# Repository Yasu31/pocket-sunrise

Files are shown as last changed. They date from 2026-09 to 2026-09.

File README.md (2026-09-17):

# Pocket Sunrise
[English README](/README-en.md)

自然な明かりで朝起きれる小型デバイス

ここではファームウェアのArduinoスケッチと基板デザイン(KiCad)を公開しています
- プロジェクト: https://yasunori.jp/pocket-sunrise
- 外装部品: https://grabcad.com/library/pocket-sunrise-1
- 動画: https://youtu.be/eCHGJ3ehzJc

## キャンドルライトモード

3つのボタンを同時に押すと、タイマーの状態に関わらずLEDが点灯し、ろうそくのように明るさがかすかに変化するモードに切り替えられます。左右のボタンで明るさを調整できます。

## 電子部品
必要な電子パーツはこちらのスプレッドシートにまとめてあります。すべて秋月電子で買えます。
 →[Pocket Sunrise 電子部品](https://docs.google.com/spreadsheets/d/1AGpVGOaxi01ax8kF4fcREE8NY4uzkjkZFQBg4IJ91os/edit?usp=sharing)

## 基板
私はPCBGOGOに発注しましたがどこでも大丈夫だと思います。5枚発注して（初回割ということもありましたが）送料込みでたった1200円でした。

## 基板実装
以下の写真を参考に実装してください。注意点としては
- LEDの定格内で扱っていて、抵抗での発熱も許容範囲のはずですが、それでも想定外のケースなどで異常発熱する場合もあり得るので、使用時は常にそばにいる状態にしてください。自己責任で使ってください。
- 7セグ用の300Ω抵抗は基板画像の通り一部のみ実装し、それ以外は短絡してください（7セグの向きを後から変えられるようにこの実装になっています）。
- LEDの定格電流的には25Ωの電流制限抵抗は全然許容範囲内なのですが、セメント抵抗の方の発熱が大きかったので、50Ω抵抗を並列で接続して放熱板も取り付けることで発熱を抑えています。画像のように組付ければ、外装パーツ内に収まるはずです（もちろんちゃんとしたLEDドライバを使えば発熱を抑えられるのですが、初めての基板設計ということもあり簡単な回路を優先しました）
- Arduino nanoが基板に挿さったままだとスケッチが書き込めない場合があります。うまく書き込めない場合は、一旦抜いてから書き込んでください。
- LEDは10センチほどのワイヤで基板に接続してください。曲げやすいワイヤの方が外装パーツに挿入しやすいです。
- LEDの裏側にも放熱板を取り付けることをお勧めします。
- M3、長さ12mmのナットとボルト4本で組み立てられます。ゴム足パーツを底に貼ると滑り止めになります。






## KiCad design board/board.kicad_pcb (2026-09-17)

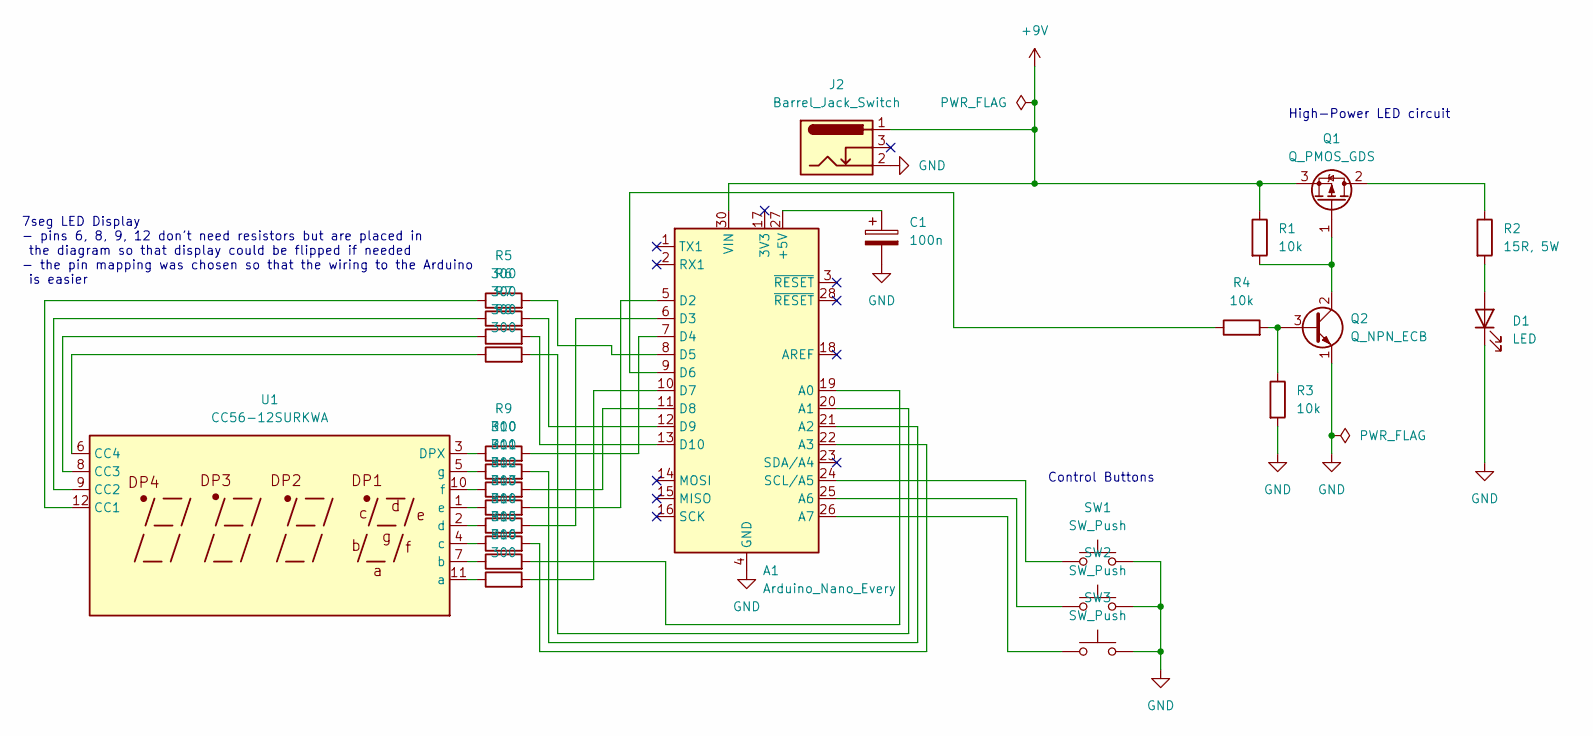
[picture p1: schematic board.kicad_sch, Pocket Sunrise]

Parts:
A1: Arduino_Nano_Every; Arduino_Nano
C1: 100n; C_Disc_D7.0mm_W2.5mm_P5.00mm
D1: LED; PinHeader_1x02_P2.54mm_Vertical
J2: Barrel_Jack_Switch; BarrelJack_Horizontal
Q1: Q_PMOS_GDS; TO-220-3_Horizontal_TabDown
Q2: Q_NPN_ECB; TO-92
R1, R3, R4: 10k; R_Axial_DIN0207_L6.3mm_D2.5mm_P10.16mm_Horizontal
R2: 15R, 5W; R_Axial_Power_L20.0mm_W6.4mm_P30.48mm
R5, R6, R7, R8, R9, R10, R11, R12, R13, R14, R15, R16: 300; R_Axial_DIN0207_L6.3mm_D2.5mm_P10.16mm_Horizontal
SW1, SW2, SW3: SW_Push; SW_PUSH_6mm_H7.3mm
U1: CC56-12SURKWA; CA56-12SURKWA

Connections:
+9V: A1.30 (VIN), J2.1, Q1.3 (S), R1.1
GND: A1.4 (GND), A1.29 (GND), C1.2, D1.1 (K), J2.2, Q2.1 (E), R3.2, SW1.2, SW2.2, SW3.2
unnamed: A1.27 (+5V), C1.1
unnamed: A1.19 (A0), R15.2
unnamed: A1.20 (A1), R8.2
unnamed: A1.21 (A2), R10.2
unnamed: A1.22 (A3), R14.2
unnamed: A1.25 (A6), SW2.1
unnamed: A1.26 (A7), SW3.1
unnamed: A1.5 (D2), R12.2
unnamed: A1.6 (D3), R13.2
unnamed: A1.7 (D4), R9.2
unnamed: A1.8 (D5), R5.2
unnamed: A1.9 (D6), R4.1
unnamed: A1.10 (D7), R16.2
unnamed: A1.11 (D8), R11.2
unnamed: A1.12 (D9), R6.2
unnamed: A1.13 (D10), R7.2
unnamed: A1.24 (SCL/A5), SW1.1
unnamed: D1.2 (A), R2.2
unnamed: Q1.2 (D), R2.1
unnamed: Q1.1 (G), Q2.2 (C), R1.2
unnamed: Q2.3 (B), R3.1, R4.2
unnamed: R5.1, U1.12 (CC1)
unnamed: R6.1, U1.9 (CC2)
unnamed: R7.1, U1.8 (CC3)
unnamed: R8.1, U1.6 (CC4)
unnamed: R9.1, U1.3 (DPX)
unnamed: R16.1, U1.11 (a)
unnamed: R15.1, U1.7 (b)
unnamed: R14.1, U1.4 (c)
unnamed: R13.1, U1.2 (d)
unnamed: R12.1, U1.1 (e)
unnamed: R11.1, U1.10 (f)
unnamed: R10.1, U1.5 (g)

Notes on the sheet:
7seg LED Display - pins 6, 8, 9, 12 don't need resistors but are placed in the diagram so that display could be flipped if needed - the pin mapping was chosen so that the wiring to the Arduino is easier
High-Power LED circuit
Control Buttons

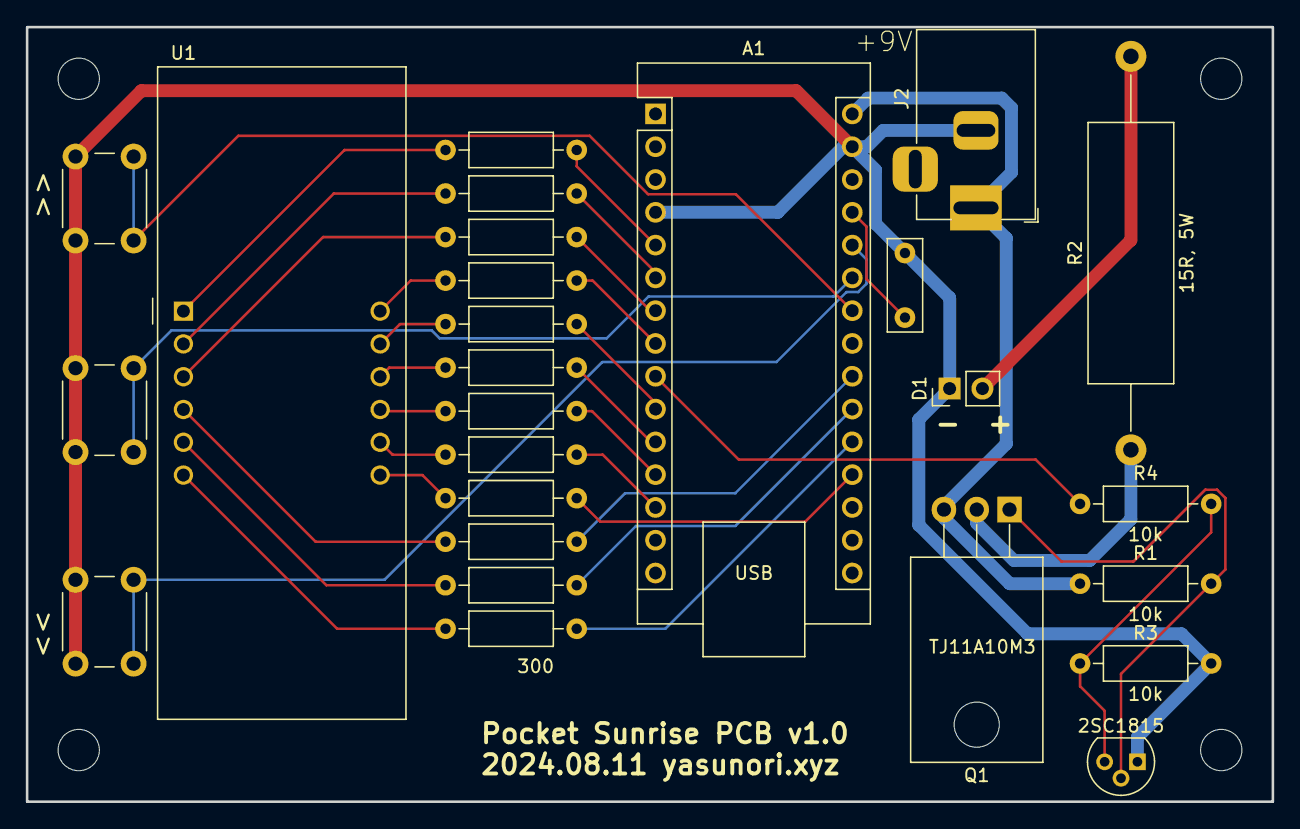
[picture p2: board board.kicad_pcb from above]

Board: 2 copper layers, 96.5 x 60.0 mm, 26 parts (0 on the bottom side), 35 nets.

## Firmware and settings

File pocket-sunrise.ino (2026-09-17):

#include <Arduino.h>
#include <math.h>
#include <util/atomic.h>
#include "SevSeg.h"

#if !defined(ARDUINO_AVR_NANO_EVERY) || !defined(MILLIS_USE_TIMERB3)
#error "Select Arduino Nano Every with the official Arduino megaAVR Boards core."
#endif

SevSeg sevseg; // Instantiate a seven-segment object

// Timer variables
unsigned long setDuration = 7UL * 60 * 60 * 1000; // User-set duration
unsigned long remainingTime = setDuration;        // Remaining time in milliseconds
unsigned long lastTimerUpdateTime = 0;
unsigned long currentMillis = 0;
bool timerPaused = true;

// Display variables
unsigned long lastInteractionTime = 0;
bool displayOn = true;
unsigned long lastBlinkTime = 0;
bool displayBlinkState = true;

// Center button long press duration in milliseconds
const unsigned long LONG_PRESS_DURATION = 1000;

// LED brightness variables
float currentBrightness = 0.0f;
const unsigned long BRIGHTNESS_UPDATE_INTERVAL = 10; // milliseconds
const float BRIGHTNESS_SMOOTHING_TIME = 500.0f;       // milliseconds
bool candlelightOn = false;
int candlelightLevel = 80; // User setting, retained when toggling the mode.
float candlelightTarget = 0.985f;
unsigned long lastCandlelightChangeTime = 0;
unsigned long candlelightChangeInterval = 0;

// LED auto-off variables. Keep the light off until a new session starts.
unsigned long ledAutoOffStartTime = 0;
bool ledAutoOffArmed = false;
bool ledAutoOff = false;
const unsigned long LED_AUTO_OFF_DURATION = 60UL * 60 * 1000;

// Constants for acceleration effect
const unsigned long BASE_INTERVAL = 300; // Initial interval between increments (at start)
const unsigned long MIN_INTERVAL = 10;   // Minimum interval between increments (after pressing for long time)
const unsigned long MAX_PRESS_DURATION = 4000;

// pin assignments
const int buttonPin_l = 19;
const int buttonPin_c = 20;
const int buttonPin_r = 21;
const int ledPin = 6; // Nano Every D6 = PF4 = TCB0 output

// The core's TCA0 runs at CPU / 64 with a 256-count period. Leave that
// configuration alone: other Arduino timers use its clock for timekeeping.
// TCB0 runs at the full CPU clock, giving nominally 16384 pulse-width steps
// per period (about 977 Hz at 16 MHz), instead of analogWrite()'s 256 steps.
const uint16_t LED_PWM_PERIOD = 16384;
volatile uint16_t ledPulseTicks = 0;

void setupLedPwm() {
  pinMode(ledPin, OUTPUT);
  digitalWrite(ledPin, LOW);

  PORTMUX.TCBROUTEA |= PORTMUX_TCB0_bm; // Route TCB0 to PF4/D6.
  TCB0.CTRLA = 0;
  TCB0.CTRLB = TCB_CNTMODE_SINGLE_gc;
  TCB0.EVCTRL = 0;
  TCB0.INTCTRL = 0;
  TCB0.INTFLAGS = TCB_CAPT_bm;

  // Use the existing TCA0 overflow only as a pulse-start tick.
  // TCB3 (millis/micros), TCA0's clock, and the display pins are unchanged.
  TCA0.SINGLE.INTFLAGS = TCA_SINGLE_OVF_bm;
  TCA0.SINGLE.INTCTRL |= TCA_SINGLE_OVF_bm;
}

ISR(TCA0_OVF_vect) {
  TCA0.SINGLE.INTFLAGS = TCA_SINGLE_OVF_bm;
  const uint16_t ticks = ledPulseTicks;

  // Re-arm only at the start of a period. Never change CCMP mid-pulse:
  // lowering it below CNT could otherwise produce an unexpectedly long pulse.
  TCB0.CTRLA = 0;

  if (ticks >= LED_PWM_PERIOD) {
    PORTF.OUTSET = PIN4_bm;
    TCB0.CTRLB = TCB_CNTMODE_SINGLE_gc; // Steady HIGH, no timer output.
    return;
  }

  PORTF.OUTCLR = PIN4_bm;
  TCB0.CTRLB = TCB_CNTMODE_SINGLE_gc; // Steady LOW when ticks == 0.
  if (ticks == 0) return;

  TCB0.CCMP = ticks;
  TCB0.CNT = 0;
  TCB0.CTRLB = TCB_CNTMODE_SINGLE_gc | TCB_CCMPEN_bm;
  // Enabling single-shot mode with CNT < CCMP starts one pulse. Hardware
  // ends it. Interrupt latency can shift its start, not extend a low-duty pulse.
  TCB0.CTRLA = TCB_CLKSEL_CLKDIV1_gc | TCB_ENABLE_bm;
}

void writeLedPwm(uint16_t ticks) {
  if (ticks > LED_PWM_PERIOD) ticks = LED_PWM_PERIOD;
  // A 16-bit write is not atomic on this 8-bit MCU.
  ATOMIC_BLOCK(ATOMIC_RESTORESTATE) {
    ledPulseTicks = ticks;
  }
}

uint16_t convertToPWM(float brightnessValue) {
  // Zero-anchored exponential curve: 0 -> off, 1 -> fully on.
  // Keep fractional precision until the final 14-bit rounding step.
  if (!(brightnessValue > 0.0f)) return 0;
  if (brightnessValue >= 1.0f) return LED_PWM_PERIOD;
  const float exponentialRange = 147.4131591f; // exp(5) - 1
  const float duty = (expf(5.0f * brightnessValue) - 1.0f) / exponentialRange;
  return (uint16_t)(duty * LED_PWM_PERIOD + 0.5f);
}

// Button class to handle debouncing and state
class Button {
public:
  int pin;
  bool state;
  bool lastState;
  unsigned long lastDebounceTime;
  bool lastButtonPushed;
  unsigned long pressStartTime;
  bool ignoreCurrentPress;
  unsigned long lastIncrementTime;

  Button(int pin) : pin(pin), state(HIGH), lastState(HIGH), lastDebounceTime(0),
                    lastButtonPushed(false), pressStartTime(0),
                    ignoreCurrentPress(false), lastIncrementTime(0) {}

  bool checkButton() {
    // check the button state, with debouncing
    // returns true at the moment the button is pressed down
    const unsigned long debounceDelay = 50;
    int reading = digitalRead(pin);

    if (reading != lastState) {
      lastDebounceTime = currentMillis;
    }

    if ((currentMillis - lastDebounceTime) > debounceDelay) {
      if (reading != state) {
        state = reading;
        if (state == LOW) {
          return true; // Button down event
        }
      }
    }

    lastState = reading;
    return false;
  }

  bool isPressed() {
    return state == LOW;
  }

  bool isReleased() {
    return (!isPressed() && lastButtonPushed);
  }

  void updateLastButtonPushed() {
    lastButtonPushed = isPressed();
  }
};

// Instantiate button objects
Button leftButton(buttonPin_l);
Button centerButton(buttonPin_c);
Button rightButton(buttonPin_r);

// Explicit declarations also keep Arduino's sketch preprocessor happy.
void handleAdjustment(Button &button, bool isIncrement, bool pressed);
void handleCenterButton(Button &button, bool pressed);

void setup() {
  byte numDigits = 4;
  byte digitPins[] = {5, 9, 10, 15};
  byte segmentPins[] = {7, 14, 17, 3, 2, 8, 16, 4};
  bool resistorsOnSegments = false; // 'false' means resistors are on digit pins
  byte hardwareConfig = COMMON_ANODE;
  bool updateWithDelays = false;
  bool leadingZeros = false;
  bool disableDecPoint = false;
  sevseg.begin(hardwareConfig, numDigits, digitPins, segmentPins,
               resistorsOnSegments, updateWithDelays, leadingZeros,
               disableDecPoint);

  setupLedPwm(); // Do not use analogWrite/digitalWrite on D6 after this.
  pinMode(leftButton.pin, INPUT_PULLUP);
  pinMode(centerButton.pin, INPUT_PULLUP);
  pinMode(rightButton.pin, INPUT_PULLUP);

  lastInteractionTime = millis();

  // Serial print for debugging
  // don't use serial print on final uploaded code, since it delays the loop
  // Serial.begin(115200);
}

void adjustCandlelight(bool isIncrement) {
  candlelightLevel = constrain(candlelightLevel + (isIncrement ? 1 : -1), 0, 100);
  candlelightChangeInterval = 0; // Apply the new range on the next LED update.
}

void handleAdjustment(Button &button, bool isIncrement, bool pressed) {
  // isIncrement: true for the increment button, false for the decrement button
  if (pressed) {
    // Allow the other buttons to settle before the first adjustment.
    button.lastIncrementTime = currentMillis;
    lastInteractionTime = currentMillis;
    if (!displayOn) {
      displayOn = true;
      button.ignoreCurrentPress = true;
    } else {
      button.pressStartTime = currentMillis;
      button.ignoreCurrentPress = false;
    }
  }

  if (displayOn && !button.ignoreCurrentPress && button.isPressed() &&
      (candlelightOn || timerPaused)) {
    unsigned long pressDuration = currentMillis - button.pressStartTime;
    // shorten the interval time between each step, the longer the button is pressed
    unsigned long interval = BASE_INTERVAL -
                             (BASE_INTERVAL - MIN_INTERVAL) *
                                 constrain((float)pressDuration /
                                               MAX_PRESS_DURATION,
                                           0, 1);
    interval = constrain(interval, MIN_INTERVAL, BASE_INTERVAL);

    if ((currentMillis - button.lastIncrementTime) >= interval) {
      if (candlelightOn) {
        adjustCandlelight(isIncrement);
      } else {
        unsigned long adjustAmount = 1UL * 60 * 1000; // 1 minute
        if (isIncrement) {
          remainingTime += adjustAmount;
        } else {
          remainingTime = remainingTime >= adjustAmount
                              ? remainingTime - adjustAmount
                              : 0;
        }
        setDuration = remainingTime; // Update setDuration
      }
      button.lastIncrementTime = currentMillis;
    }
    lastInteractionTime = currentMillis;
  }

  if (button.isReleased()) {
    // A short candlelight tap still changes one step after chord detection.
    if (candlelightOn && !button.ignoreCurrentPress &&
        button.lastIncrementTime == button.pressStartTime) {
      adjustCandlelight(isIncrement);
      lastInteractionTime = currentMillis;
    }
    button.pressStartTime = 0;
    button.ignoreCurrentPress = false;
  }

  button.updateLastButtonPushed();
}

void handleCenterButton(Button &button, bool pressed) {
  static bool centerButtonLongPressHandled = false;
  static unsigned long centerButtonPressTime = 0;

  if (candlelightOn) {
    // In candlelight mode the center button only shows the brightness setting.
    if (button.isPressed()) {
      lastInteractionTime = currentMillis;
      displayOn = true;
    }
    button.updateLastButtonPushed();
    return;
  }

  if (pressed) {
    centerButtonPressTime = currentMillis;
    centerButtonLongPressHandled = false;
    lastInteractionTime = currentMillis;
    if (!displayOn) {
      displayOn = true;
      button.ignoreCurrentPress = true;
    } else {
      button.ignoreCurrentPress = false;
    }
  }

  if (displayOn && !button.ignoreCurrentPress && button.isPressed()) {
    if (!centerButtonLongPressHandled) {
      unsigned long pressDuration = currentMillis - centerButtonPressTime;
      if (pressDuration >= LONG_PRESS_DURATION) {
        // Long press detected
        centerButtonLongPressHandled = true;
        remainingTime = setDuration; // Reset to previously set duration
        timerPaused = true;
        ledAutoOffArmed = false;
        ledAutoOff = false;
        lastInteractionTime = currentMillis;
        displayOn = true;
      }
    }
  }

  if (button.isReleased()) {
    unsigned long pressDuration = currentMillis - centerButtonPressTime;
    if (displayOn && !centerButtonLongPressHandled &&
        pressDuration < LONG_PRESS_DURATION && !button.ignoreCurrentPress) {
      // Short press detected
      timerPaused = !timerPaused; // Toggle pause/restart
      if (!timerPaused) {
        ledAutoOffArmed = false;
        ledAutoOff = false;
      }
      lastInteractionTime = currentMillis;
    }
    centerButtonPressTime = 0;
    button.ignoreCurrentPress = false;
  }

  button.updateLastButtonPushed();
}

void handleButtons() {
  static bool chordActive = false;
  // Sample all debounced states before dispatching individual actions.
  bool leftPressed = leftButton.checkButton();
  bool centerPressed = centerButton.checkButton();
  bool rightPressed = rightButton.checkButton();
  bool allPressed = leftButton.isPressed() && centerButton.isPressed() &&
                    rightButton.isPressed();
  if (allPressed && !chordActive) {
    candlelightOn = !candlelightOn;
    candlelightChangeInterval = 0; // Pick a fresh flicker target on entry.
    chordActive = true;
    displayOn = true;
    lastInteractionTime = currentMillis;
  }
  if (chordActive) {
    // Consume the whole gesture, including staggered releases and long holds.
    leftButton.updateLastButtonPushed();
    centerButton.updateLastButtonPushed();
    rightButton.updateLastButtonPushed();
    if (!leftButton.isPressed() && !centerButton.isPressed() &&
        !rightButton.isPressed()) {
      chordActive = false;
    }
    return;
  }
  handleAdjustment(leftButton, false, leftPressed);
  handleAdjustment(rightButton, true, rightPressed);
  handleCenterButton(centerButton, centerPressed);
}

void updateTimer() {
  if (!timerPaused && (currentMillis - lastTimerUpdateTime >= 1000)) {
    remainingTime = remainingTime >= 1000 ? remainingTime - 1000 : 0;

    if (remainingTime == 0) {
      timerPaused = true; // Stop the timer when it reaches zero
      ledAutoOffStartTime = currentMillis;
      ledAutoOffArmed = true;
      ledAutoOff = false;
    }
    lastTimerUpdateTime = currentMillis;
  }
}

void updateDisplay() {
  if (candlelightOn) {
    if (displayOn) {
      sevseg.setNumber(candlelightLevel); // Plain 0..100, without a decimal point.
    } else {
      sevseg.blank();
    }
    return;
  }

  // Handle display blinking when paused
  // don't blink if the time is being adjusted (i.e. left or right button is pressed)
  if (timerPaused && !(leftButton.isPressed() || rightButton.isPressed())) {
    if (currentMillis - lastBlinkTime >= 300) {
      displayBlinkState = !displayBlinkState;
      lastBlinkTime = currentMillis;
    }
  } else {
    displayBlinkState = true;
  }

  if (displayOn) {
    if (displayBlinkState) {
      // e.g. 8 hours 10 mins -> show as "08.10" on the display
      unsigned long totalMinutes = remainingTime / 60000UL;
      unsigned int hours = totalMinutes / 60;
      unsigned int minutes = totalMinutes % 60;
      int displayNumber = hours * 100 + minutes;
      sevseg.setNumber(displayNumber, 2);
    } else {
      sevseg.blank();
    }
  } else {
    sevseg.blank();
  }
}

void updateBrightness() {
  // Limit the expensive math to 100 Hz; pulse widths are timed in hardware.
  static unsigned long lastBrightnessUpdateTime = 0;
  unsigned long elapsed = currentMillis - lastBrightnessUpdateTime;
  if (elapsed < BRIGHTNESS_UPDATE_INTERVAL) return;
  lastBrightnessUpdateTime = currentMillis;

  const unsigned long rampdown_dur = 10UL * 60 * 1000; // "sunset"
  const unsigned long rampup_dur = 20UL * 60 * 1000;   // "sunrise"
  float targetMaxBrightness = 0.0f;

  if (remainingTime <= rampup_dur) {
    targetMaxBrightness = (rampup_dur - remainingTime) / (float)rampup_dur;
    targetMaxBrightness = constrain(targetMaxBrightness, 0.0f, 1.0f);
  }
  else if ((setDuration - remainingTime) <= rampdown_dur && !timerPaused) {
    targetMaxBrightness = 1.0f - (setDuration - remainingTime) / (float)rampdown_dur;
    targetMaxBrightness *= 0.2f; // Sunset is dimmer, but now fades all the way to 0.
  }

  // Preserve the gentle 10-second pulse between 50% and 100% brightness.
  // Reduce the time before converting to float to keep phase precision after days.
  float phase = (currentMillis % 10000UL) / 10000.0f;
  float sineFactor = (sin(2.0f * PI * phase) + 1.0f) / 2.0f;
  float targetBrightness = targetMaxBrightness * (0.5f + 0.5f * sineFactor);

  if (displayOn)
    targetBrightness = constrain(targetBrightness, 0.0f, 0.03f);

  // Elapsed-time subtraction handles millis() rollover. Latch the off state;
  // clearing only the timer would let the sunrise logic relight the next loop.
  if (ledAutoOffArmed &&
      currentMillis - ledAutoOffStartTime >= LED_AUTO_OFF_DURATION) {
    ledAutoOffArmed = false;
    ledAutoOff = true;
  }
  if (ledAutoOff) targetBrightness = 0.0f;

  // Candlelight overrides the normal LED output while the timer keeps running.
  // Slide a 50-unit target window from 0..50 to 950..1000 (inclusive).
  if (candlelightOn) {
    if (currentMillis - lastCandlelightChangeTime >= candlelightChangeInterval) {
      long minimumTarget = candlelightLevel * 950L / 100;
      candlelightTarget = random(minimumTarget, minimumTarget + 51L) / 1000.0f;
      candlelightChangeInterval = random(200L, 400L);
      lastCandlelightChangeTime = currentMillis;
    }
    targetBrightness = candlelightTarget;
  }

  // Time-based smoothing, independent of display refresh speed / loop rate.
  float smoothingTime = candlelightOn ? 120.0f : BRIGHTNESS_SMOOTHING_TIME;
  float alpha = elapsed / (smoothingTime + elapsed);
  currentBrightness += alpha * (targetBrightness - currentBrightness);

  uint16_t pwmValue = convertToPWM(currentBrightness);
  if (targetBrightness == 0.0f && pwmValue == 0) currentBrightness = 0.0f;
  writeLedPwm(pwmValue);
}

void checkInactivity() {
  // Turn off the display after 10 seconds of no interaction
  displayOn = (currentMillis - lastInteractionTime < 10000);
}

void loop() {
  currentMillis = millis();
  sevseg.refreshDisplay();

  // Handle buttons
  handleButtons();

  // Update timer and display
  updateTimer();
  updateDisplay();
  updateBrightness();
  checkInactivity();
}

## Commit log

2026-09-16 Add high-resolution Nano Every LED pulses and a zero-anchored fade
2026-09-16 Preserve center-button timing and clarify pulse timing guarantees
2026-09-16 Use the existing center-button pin constant
2026-09-17 rename so Arduino IDE can directly open
2026-09-17 rename across project
    [board.kicad_pcb, board.kicad_sch]
2026-09-17 button adjust for candlelight mode
2026-09-17 add about heatsink behind LEDs
